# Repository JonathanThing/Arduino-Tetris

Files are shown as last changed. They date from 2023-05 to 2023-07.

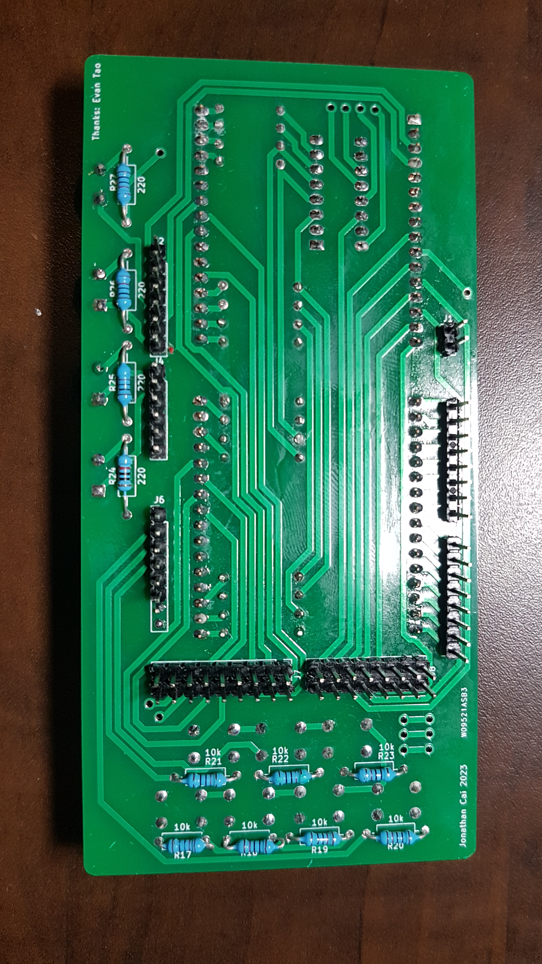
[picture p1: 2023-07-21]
Pictures/Soldered Back PCB.jpg

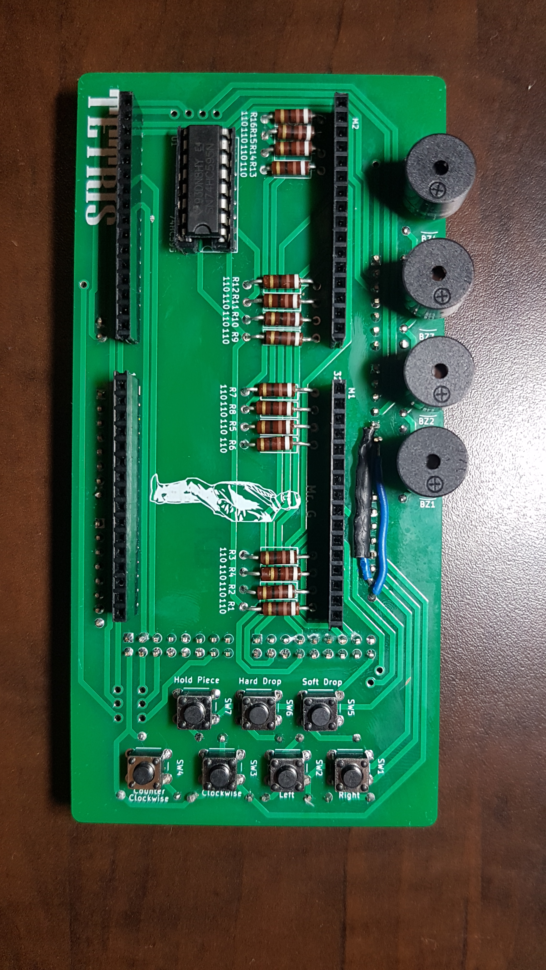
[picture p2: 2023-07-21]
Pictures/Soldered Front PCB.jpg

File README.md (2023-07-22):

# Arduino-Tetris
Tetris on an Arduino Mega

Video Demo: <br />
Arduino Tetris Demo (https://www.youtube.com/watch?v=_YhfdDc1tRE)

This was my Gr.12 Computer Engineering Final project where I designed, created, and programmed Tetris from start to finish.

Software Used:
- KiCAD
- Arduino IDE

Stage 1: Design
- Using KiCad, I created a circuit diagram and PCB layout

Stage 2: Assembly
- I soldered the components onto the PCB, 

Stage 3: Programming
- I programmed Tetris and the music player

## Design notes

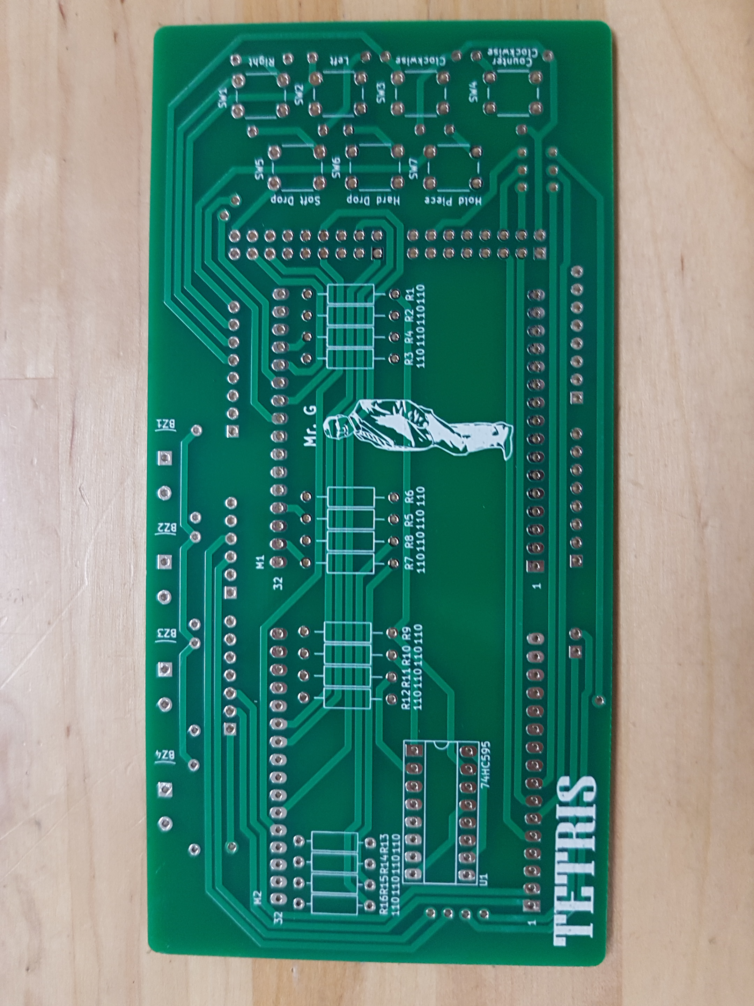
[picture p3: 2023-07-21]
Pictures/Front PCB.jpg

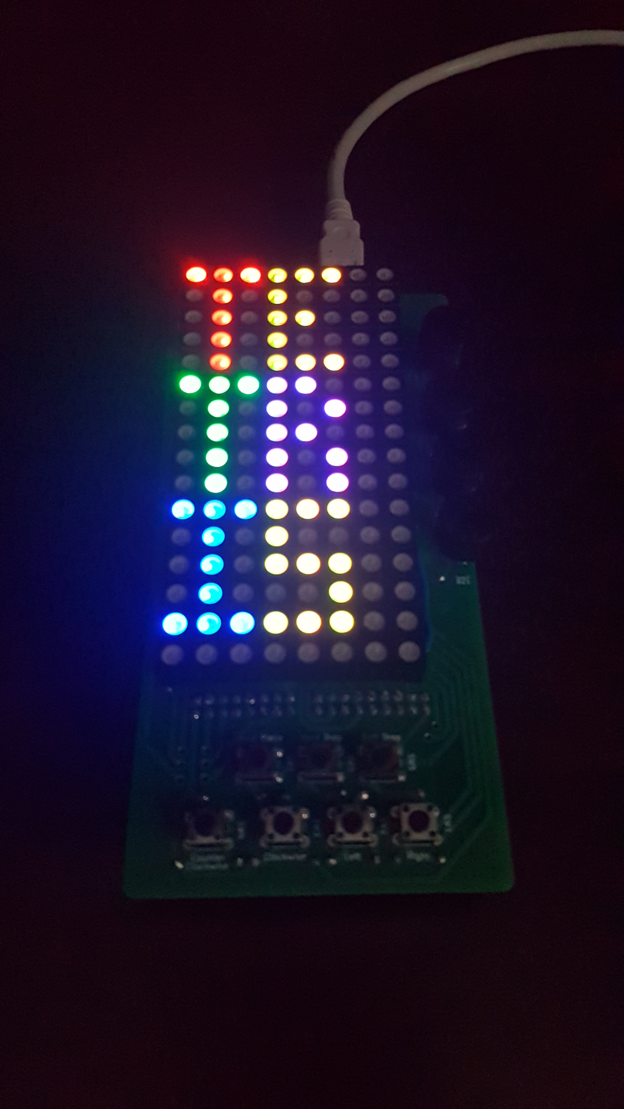
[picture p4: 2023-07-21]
Pictures/Final Project.jpg

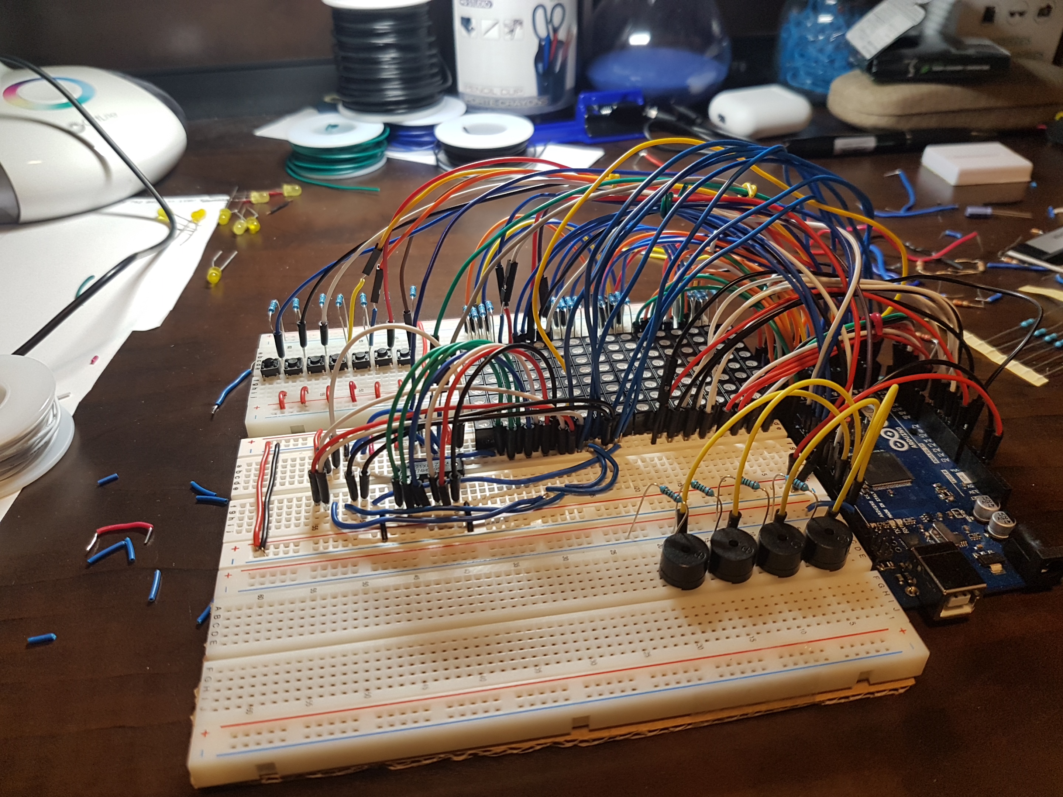
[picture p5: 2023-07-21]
Pictures/Prototype.jpg

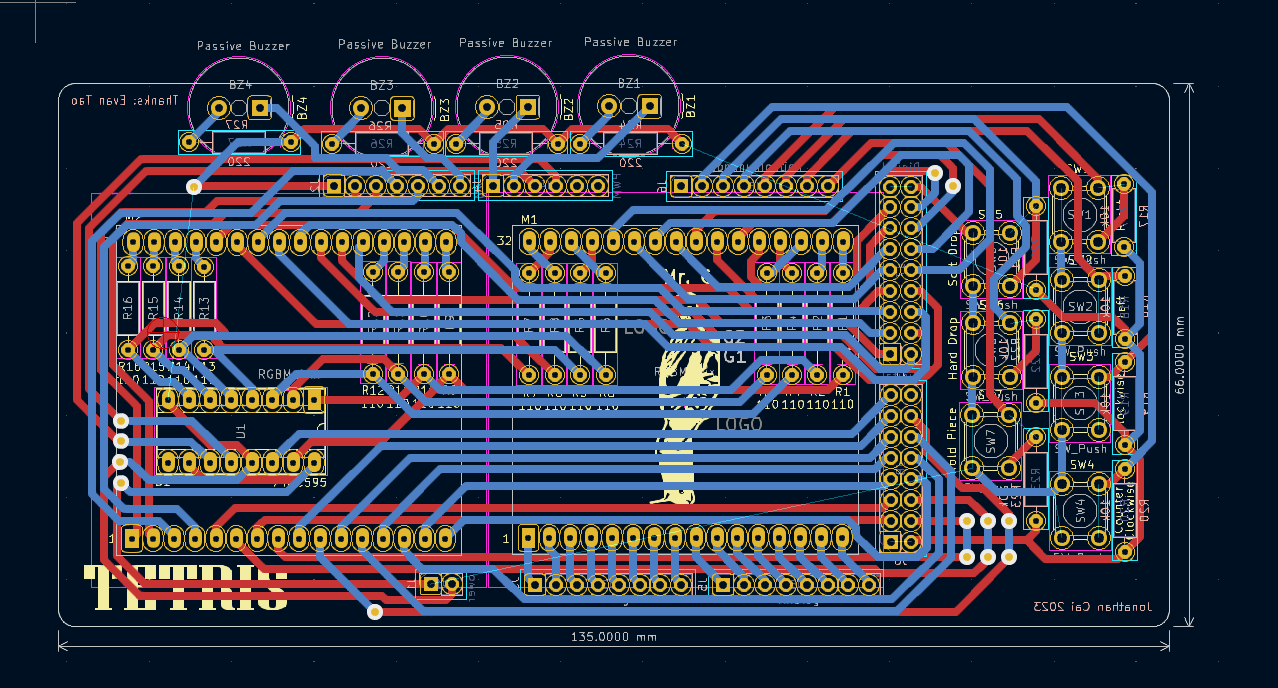
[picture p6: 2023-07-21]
Pictures/PCB Layout.png

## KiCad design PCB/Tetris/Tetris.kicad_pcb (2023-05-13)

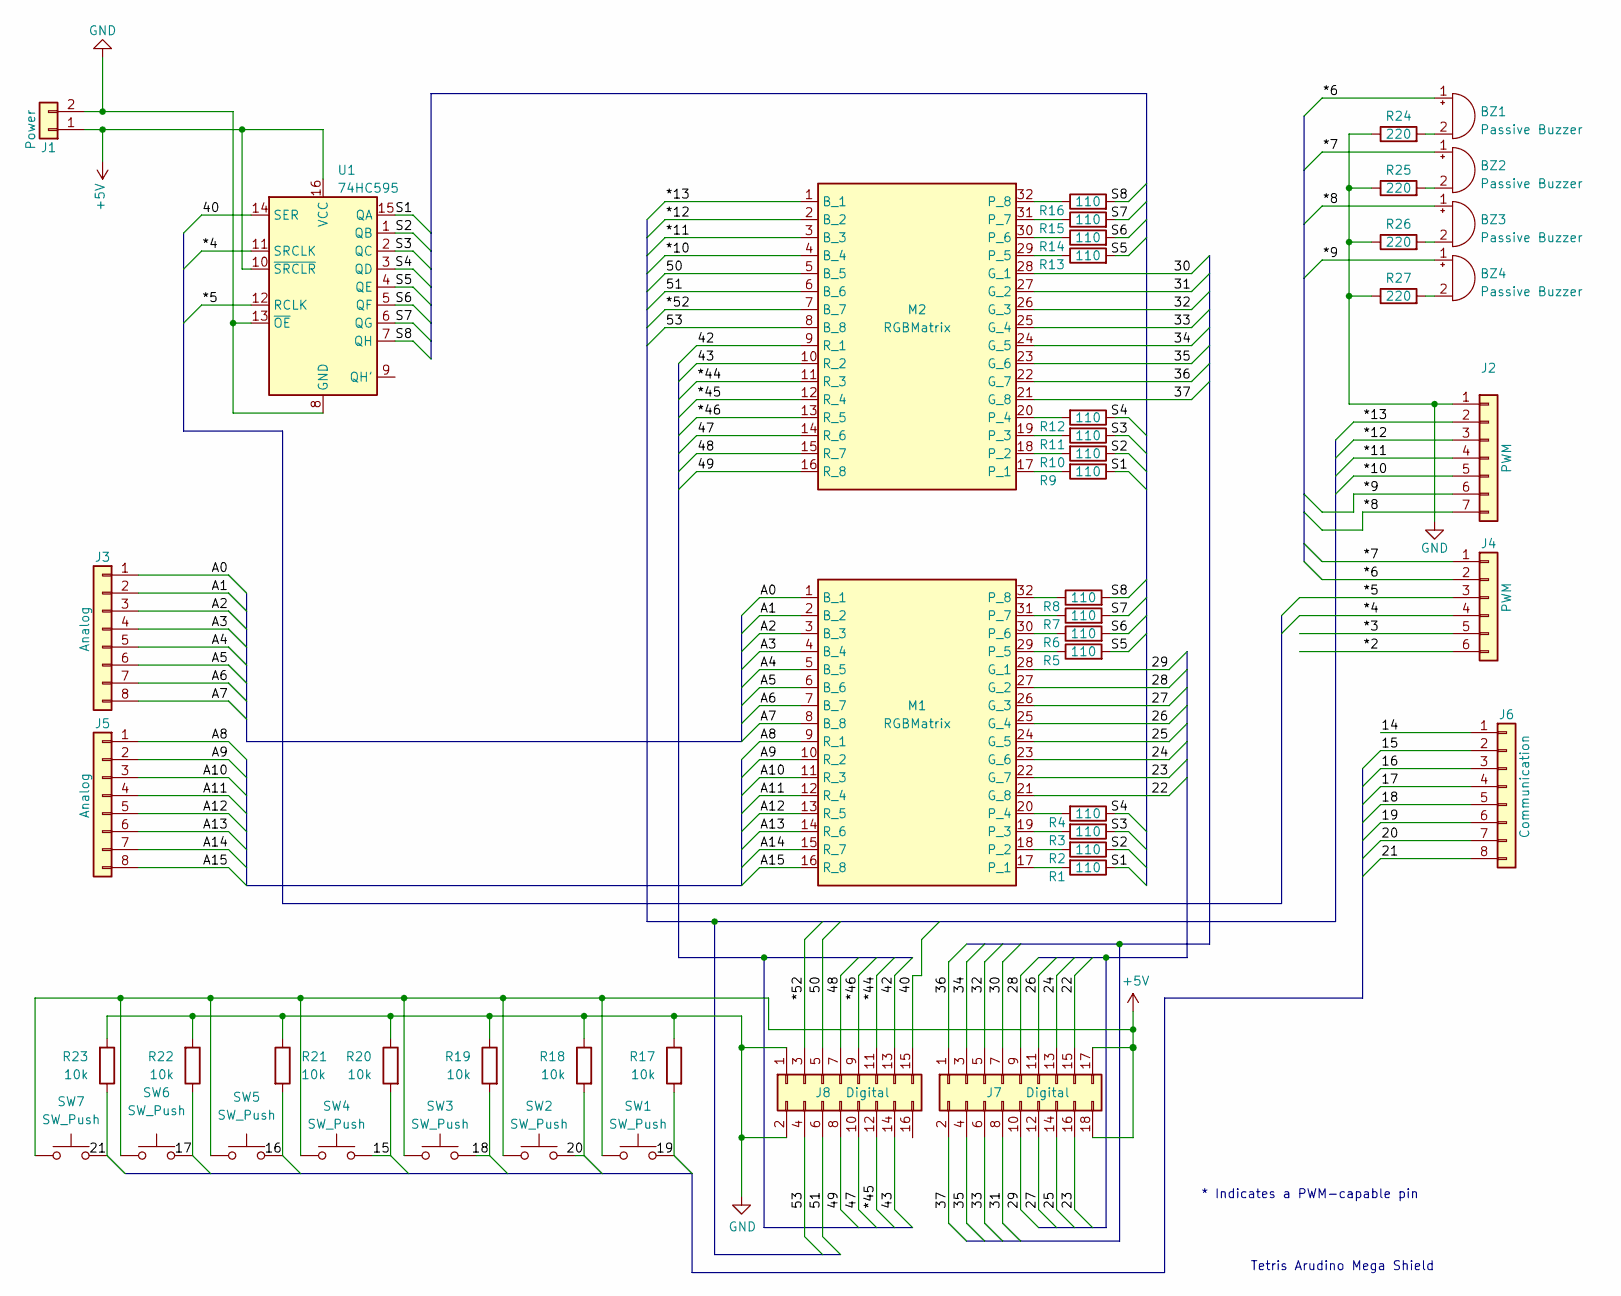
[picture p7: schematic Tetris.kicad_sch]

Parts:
BZ1, BZ2, BZ3, BZ4: Passive Buzzer; Buzzer_TDK_PS1240P02BT_D12.2mm_H6.5mm
J1: Power; PinHeader_1x02_P2.54mm_Vertical
J2: PWM; PinHeader_1x07_P2.54mm_Vertical
J3, J5: Analog; PinHeader_1x08_P2.54mm_Vertical
J4: PWM; PinHeader_1x06_P2.54mm_Vertical
J6: Communication; PinHeader_1x08_P2.54mm_Vertical
J7: Digital; PinHeader_2x09_P2.54mm_Vertical
J8: Digital; PinHeader_2x08_P2.54mm_Vertical
M1, M2: RGBMatrix
R1, R2, R3, R4, R5, R6, R7, R8, R9, R10, R11, R12: 110; R_Axial_DIN0207_L6.3mm_D2.5mm_P12.40mm_Horizontal
R13, R14, R15, R16: 110; R_Axial_DIN0207_L6.3mm_D2.5mm_P10.16mm_Horizontal
R17, R18: 10k; R_Axial_DIN0207_L6.3mm_D2.5mm_P7.62mm_Horizontal
R19, R20, R21, R22, R23: 10k; R_Axial_DIN0207_L6.3mm_D2.5mm_P10.16mm_Horizontal
R24, R25, R26, R27: 220; R_Axial_DIN0207_L6.3mm_D2.5mm_P12.40mm_Horizontal
SW1, SW2, SW3, SW4, SW5, SW6, SW7: SW_Push; SW_PUSH_6mm_H4.3mm
U1: 74HC595; DIP-16_W7.62mm_Socket_LongPads

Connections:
+5V: J1.1, J7.17, J7.18, SW1.2, SW2.2, SW3.2, SW4.2, SW5.2, SW6.2, SW7.2, U1.10 (~SRCLR), U1.16 (VCC)
/14: J6.1
/15: J6.2, R20.2, SW4.1
/16: J6.3, R21.2, SW5.1
/17: J6.4, R22.1, SW6.1
/18: J6.5, R19.2, SW3.1
/19: J6.6, R17.2, SW1.1
/20: J6.7, R18.2, SW2.1
/21: J6.8, R23.1, SW7.1
/22: J7.15, M1.21 (G_8)
/23: J7.16, M1.22 (G_7)
/24: J7.13, M1.23 (G_6)
/25: J7.14, M1.24 (G_5)
/26: J7.11, M1.25 (G_4)
/27: J7.12, M1.26 (G_3)
/28: J7.9, M1.27 (G_2)
/29: J7.10, M1.28 (G_1)
/30: J7.7, M2.28 (G_1)
/31: J7.8, M2.27 (G_2)
/32: J7.5, M2.26 (G_3)
/33: J7.6, M2.25 (G_4)
/34: J7.3, M2.24 (G_5)
/35: J7.4, M2.23 (G_6)
/36: J7.1, M2.22 (G_7)
/37: J7.2, M2.21 (G_8)
/40: J8.15, U1.14 (SER)
/41: J8.16
/42: J8.13, M2.9 (R_1)
/43: J8.14, M2.10 (R_2)
/47: J8.10, M2.14 (R_6)
/48: J8.7, M2.15 (R_7)
/49: J8.8, M2.16 (R_8)
/50: J8.5, M2.5 (B_5)
/51: J8.6, M2.6 (B_6)
/53: J8.4, M2.8 (B_8)
/*2: J4.6
/*3: J4.5
/*4: J4.4, U1.11 (SRCLK)
/*5: J4.3, U1.12 (RCLK)
/*6: BZ1.1 (-), J4.2
/*7: BZ2.1 (-), J4.1
/*8: BZ3.1 (-), J2.7
/*9: BZ4.1 (-), J2.6
/*10: J2.5, M2.4 (B_4)
/*11: J2.4, M2.3 (B_3)
/*12: J2.3, M2.2 (B_2)
/*13: J2.2, M2.1 (B_1)
/*44: J8.11, M2.11 (R_3)
/*45: J8.12, M2.12 (R_4)
/*46: J8.9, M2.13 (R_5)
/*52: J8.3, M2.7 (B_7)
/A0: J3.1, M1.1 (B_1)
/A1: J3.2, M1.2 (B_2)
/A2: J3.3, M1.3 (B_3)
/A3: J3.4, M1.4 (B_4)
/A4: J3.5, M1.5 (B_5)
/A5: J3.6, M1.6 (B_6)
/A6: J3.7, M1.7 (B_7)
/A7: J3.8, M1.8 (B_8)
/A8: J5.1, M1.9 (R_1)
/A9: J5.2, M1.10 (R_2)
/A10: J5.3, M1.11 (R_3)
/A11: J5.4, M1.12 (R_4)
/A12: J5.5, M1.13 (R_5)
/A13: J5.6, M1.14 (R_6)
/A14: J5.7, M1.15 (R_7)
/A15: J5.8, M1.16 (R_8)
/S1: R1.1, R9.1, U1.15 (QA)
/S2: R2.1, R10.1, U1.1 (QB)
/S3: R3.1, R11.1, U1.2 (QC)
/S4: R4.1, R12.1, U1.3 (QD)
/S5: R5.2, R13.2, U1.4 (QE)
/S6: R6.2, R14.2, U1.5 (QF)
/S7: R7.2, R15.2, U1.6 (QG)
/S8: R8.2, R16.2, U1.7 (QH)
GND: J1.2, J2.1, J8.1, J8.2, R17.1, R18.1, R19.1, R20.1, R21.1, R22.2, R23.2, R24.1, R25.1, R26.1, R27.1, U1.8 (GND), U1.13 (~OE)
unnamed: BZ1.2 (+), R24.2
unnamed: BZ2.2 (+), R25.2
unnamed: BZ3.2 (+), R26.2
unnamed: BZ4.2 (+), R27.2
unnamed: M1.17 (P_1), R1.2
unnamed: M1.18 (P_2), R2.2
unnamed: M1.19 (P_3), R3.2
unnamed: M1.20 (P_4), R4.2
unnamed: M1.29 (P_5), R5.1
unnamed: M1.30 (P_6), R6.1
unnamed: M1.31 (P_7), R7.1
unnamed: M1.32 (P_8), R8.1
unnamed: M2.17 (P_1), R9.2
unnamed: M2.18 (P_2), R10.2
unnamed: M2.19 (P_3), R11.2
unnamed: M2.20 (P_4), R12.2
unnamed: M2.29 (P_5), R13.1
unnamed: M2.30 (P_6), R14.1
unnamed: M2.31 (P_7), R15.1
unnamed: M2.32 (P_8), R16.1

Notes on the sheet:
* Indicates a PWM-capable pin
Tetris Arudino Mega Shield

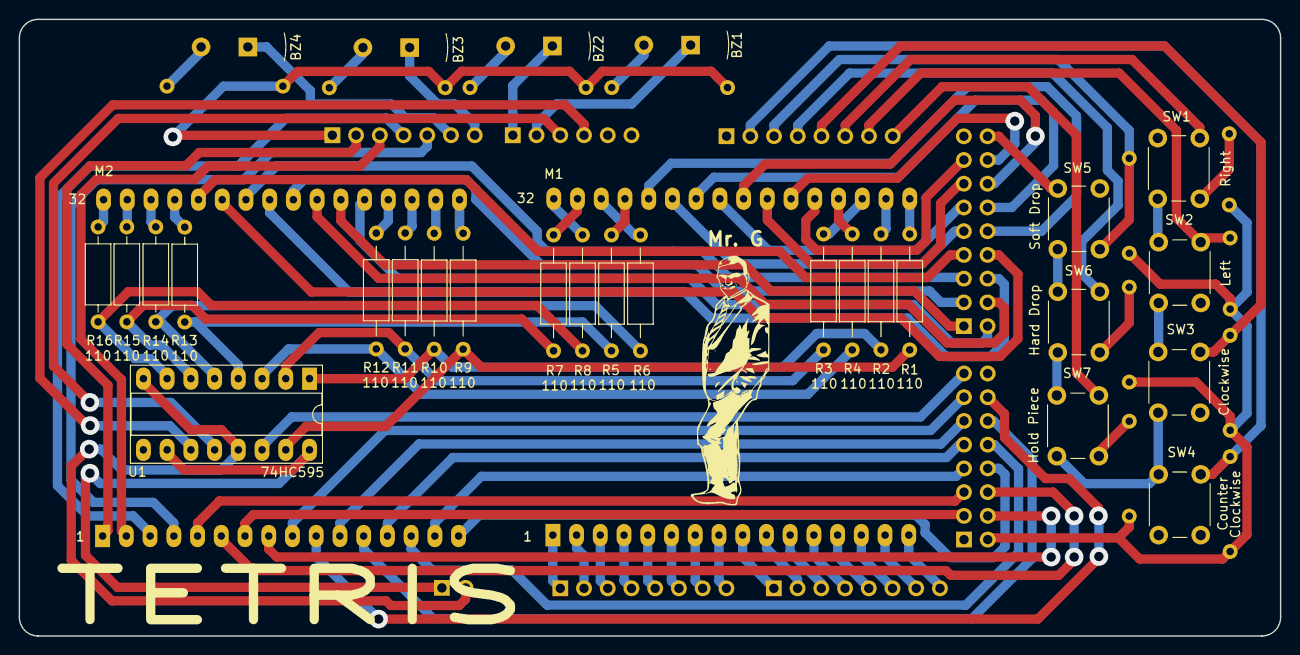
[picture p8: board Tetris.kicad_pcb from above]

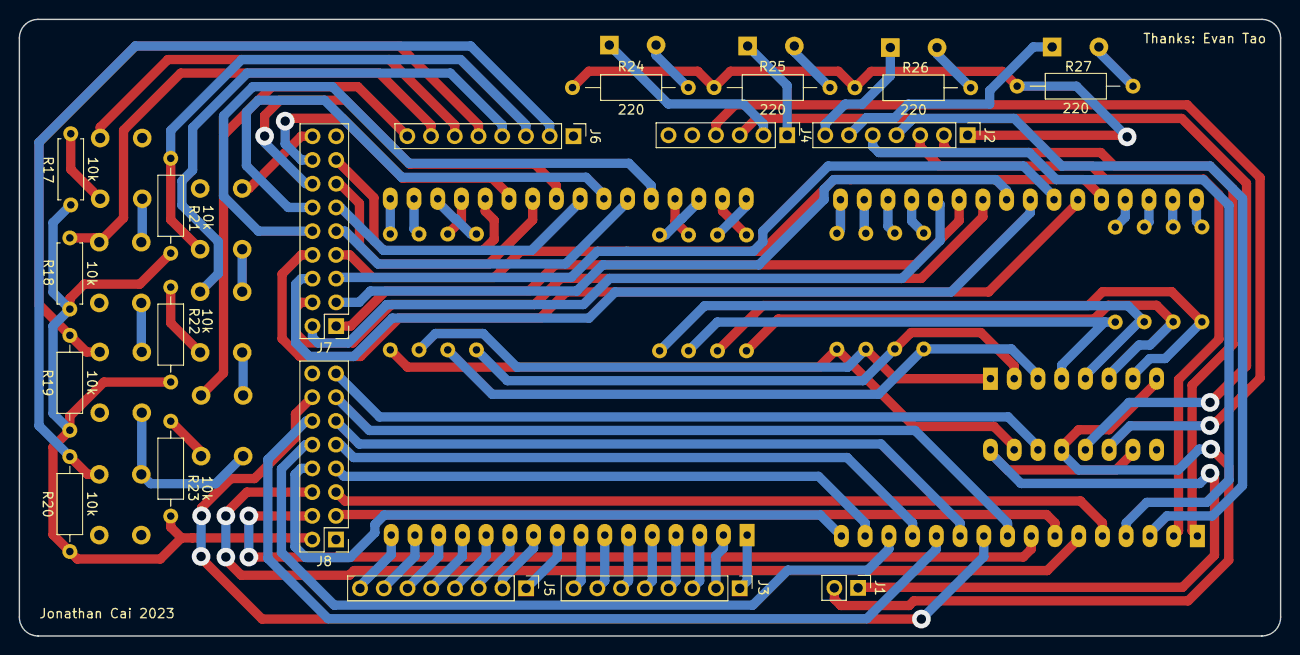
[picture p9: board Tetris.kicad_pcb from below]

Board: 2 copper layers, 135.0 x 66.0 mm, 51 parts (19 on the bottom side), 92 nets.

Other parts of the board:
G1, G2: LOGO

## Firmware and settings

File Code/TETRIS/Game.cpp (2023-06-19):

#include "Game.h"

const byte startX = 2;
const byte startY = 13;
const int defaultFallTime = 750;
int currentX = startX;
int currentY = startY;
byte currentRotation = 0;

long score = 0;
int totalLinesRemoved = 0;
int timePerFall = defaultFallTime;

byte sevenBag[7] = { 0, 1, 2, 3, 4, 5, 6 };

long inputAnchorTime = 0;  // Anchor time for user input
long fallAnchorTime = 0;   // Anchor time for falling
byte nextBlockIndex;

bool gameLost;
bool canHold;
bool emptyHold;
bool placeBlockGracePeriod;

Tetromino currentBlock = I_BLOCK;
Tetromino nextBlock = I_BLOCK;
Tetromino holdBlock = Tetromino();

char gameSpace[8][14];


void removeLines();
void adjustFallSpeed();
void randomizeBag();
void getNextBlock();
void getHoldBlock();
bool checkCollision(int x, int y, byte rotation);
int findLowestSpot();
void placeBlock();
void handleGameInput();
void moveX(int deltaX);
void moveY(int deltaY);
void rotateBlock(bool clockwise);
void hardDrop();
void drawHoldBlock();
void drawNextBlock();
void drawCurrentBlock();
void drawOutlineBlock();
void drawGameSpace();
void endGame();

void initGame(long seed) {
  // Randomizing the game
  Serial.print("Seed: ");
  Serial.println(seed);
  randomSeed(seed);
  randomizeBag();

  // Reseting Variables
  gameLost = false;
  emptyHold = true;
  canHold = true;
  nextBlockIndex = 1;
  currentBlock = blocks[sevenBag[0]];
  nextBlock = blocks[sevenBag[nextBlockIndex]];
  score = 0;
  totalLinesRemoved = 0;
  timePerFall = defaultFallTime;

  // Clearing game space
  for (int i = 0; i < 8; i++) {
    for (int j = 0; j < 14; j++) {
      gameSpace[i][j] = 0;
    }
  }
}

void updateGame() {
  long inputDeltaTime = millis() - inputAnchorTime;
  long fallDeltaTime = millis() - fallAnchorTime;

  if (fallDeltaTime > timePerFall) {
    moveY(-1);
  }
  if (inputDeltaTime > 250) {
    handleGameInput();
    if (inputs > 0) {  // If a button was pressed
      inputAnchorTime = millis();
    }
  }

  drawHoldBlock();
  drawNextBlock();
  drawGameSpace();
  drawOutlineBlock();
  drawCurrentBlock();

  if (gameLost) {
    endGame();
  }
}

void getNextBlock() {
  currentBlock = nextBlock;
  nextBlockIndex++;
  if (nextBlockIndex == 7) {
    randomizeBag();
    nextBlockIndex = 0;
  }
  nextBlock = blocks[sevenBag[nextBlockIndex]];

  // Reset Values for new Block
  placeBlockGracePeriod = true;
  canHold = true;
  currentX = startX;
  currentY = startY;
  currentRotation = 0;
  fallAnchorTime = millis();
}

void randomizeBag() {
  for (int i = 0; i < 7; i++) {
    byte index = random(7);
    byte temp = sevenBag[index];
    sevenBag[index] = sevenBag[i];
    sevenBag[i] = temp;
  }
}

void getHoldBlock() {
  if (canHold) {
    if (emptyHold) {
      emptyHold = false;
      holdBlock = currentBlock;
      getNextBlock();
    } else {
      Tetromino tempBlock = currentBlock;
      currentBlock = holdBlock;
      holdBlock = tempBlock;
      canHold = false;
    }

    // Reset Values for new Block
    placeBlockGracePeriod = true;
    currentX = startX;
    currentY = startY;
    currentRotation = 0;
    fallAnchorTime = millis();
  }
}

void handleGameInput() {
  if (inputs & 1 << 0) {  // Right
    moveX(1);
  } else if (inputs & 1 << 1) {  // Left
    moveX(-1);
  } else if (inputs & 1 << 2) {  // Clockwise
    rotateBlock(true);
  } else if (inputs & 1 << 3) {  // Counter Clockwise
    rotateBlock(false);
  } else if (inputs & 1 << 4) {  // Soft Drop
    moveY(-1);
  } else if (inputs & 1 << 5) {  // Hard Drop
    hardDrop();
  } else if (inputs & 1 << 6) {  // Hold Block
    getHoldBlock();
  }
}

// Given parameters, check if currentBlock can be there
bool checkCollision(int x, int y, byte rotation) {
  for (int rows = 0; rows < 4; rows++) {
    for (int cols = 0; cols < 4; cols++) {
      int tileX = x + cols;
      int tileY = y - rows;

      if (currentBlock.tiles[rotation] & (1 << (rows * 4 + cols))) {
        if (!(0 <= tileY && tileY <= 13 && 0 <= tileX && tileX <= 7) || gameSpace[tileX][tileY] > 0) {
          return false;
        }
      }
    }
  }

  return true;
}

void moveX(int deltaX) {
  int tempX = currentX + deltaX;
  if (checkCollision(tempX, currentY, currentRotation)) {
    currentX += deltaX;
  }
}

void moveY(int deltaY) {
  int tempY = currentY + deltaY;
  if (checkCollision(currentX, tempY, currentRotation)) {
    currentY += deltaY;
  } else {
    if (!placeBlockGracePeriod || (currentX == startX && currentY == startY)) {
      placeBlock();
    }
    placeBlockGracePeriod = false;
  }
  fallAnchorTime = millis();
}

void rotateBlock(bool clockwise) {
  byte tempRotation = currentRotation;
  if (clockwise) {
    tempRotation++;
    if (tempRotation > 3) {
      tempRotation = 0;
    }
  } else {
    tempRotation--;
    if (tempRotation > 3) {
      tempRotation = 3;
    }
  }

  if (checkCollision(currentX, currentY, tempRotation)) {
    currentRotation = tempRotation;
  }
}

void placeBlock() {
  if (currentX == startX && currentY == startY) {  // If you lose
    gameLost = true;
    return;
  }

  for (int rows = 0; rows < 4; rows++) {
    for (int cols = 0; cols < 4; cols++) {
      int tileX = currentX + cols;
      int tileY = currentY - rows;

      if (currentBlock.tiles[currentRotation] & (1 << (rows * 4 + cols))) {
        gameSpace[tileX][tileY] = currentBlock.symbol;
      }
    }
  }

  removeLines();
  getNextBlock();
}

// Remove Full lines and handles the effects of it
void removeLines() {
  // Remove Lines
  byte remainingLines[14];
  byte numberOfLines = 0;
  byte lineIndex = 0;
  for (int y = 0; y < 14; y++) {
    bool full = true;
    for (int x = 0; x < 8; x++) {
      if (gameSpace[x][y] == 0) {
        full = false;
        break;
      }
    }
    if (full) {
      numberOfLines++;
    } else {
      remainingLines[lineIndex] = y;
      lineIndex++;
    }
  }

  // Update Score, totalLinesremoved, and fall speed
  totalLinesRemoved += numberOfLines;
  adjustFallSpeed();
  switch (numberOfLines) {
    case 1:
      score += 100;
      break;
    case 2:
      score += 300;
      break;
    case 3:
      score += 500;
      break;
    case 4:
      score += 800;
      break;
  }

  // Update Display
  char tempArray[8][14];

  // Create temporary array
  for (int i = 0; i < lineIndex; i++) {
    for (int x = 0; x < 8; x++) {
      tempArray[x][i] = gameSpace[x][remainingLines[i]];
    }
  }
  for (int i = lineIndex; i < 14; i++) {
    for (int x = 0; x < 8; x++) {
      tempArray[x][i] = 0;
    }
  }

  // Trasnfer temporary array to gamespace
  for (int y = 0; y < 14; y++) {
    for (int x = 0; x < 8; x++) {
      gameSpace[x][y] = tempArray[x][y];
    }
  }
}

// Find the lowestY the current block can go to
int findLowestSpot() {
  int lowestY = currentY;
  if (!checkCollision(currentX, lowestY, currentRotation)) {
    return lowestY;
  } else {
    while (checkCollision(currentX, lowestY, currentRotation)) {
      lowestY--;
    }
    lowestY++;
    return lowestY;
  }
}
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

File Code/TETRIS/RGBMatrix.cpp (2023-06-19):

#include "RGBMatrix.h"

#define MAX_INT 0xFFFF
#define dataPin 40
#define shiftClockPin 4
#define storageClockPin 5

byte currentRow;

// Local Functions
void cyclePower();
void drawRow();
void writeColour(int colour, int value);
void writeShiftRegister(byte value);
// Helper Functions
void writeDataPin(bool value);
void writeShiftClockPin(bool value);
void writeStorageClockPin(bool value);
byte reverseByte(byte input);

void drawDisplay() {
  for (int i = 0; i < 8; i++) {
    cyclePower();
    drawRow();
  }
}

void setupRGBMatrix() {
  DDRA = B11111111;
  DDRB = B11111111;
  DDRC = B11111111;
  DDRF = B11111111;
  DDRK = B11111111;
  DDRL = B11111111;

  PORTA = B11111111;
  PORTB = B11111111;
  PORTC = B11111111;
  PORTF = B11111111;
  PORTK = B11111111;
  PORTL = B11111111;

  pinMode(dataPin, OUTPUT);
  pinMode(storageClockPin, OUTPUT);
  pinMode(shiftClockPin, OUTPUT);
  writeShiftRegister(0);
  currentRow = 0;
}

// RGB Matrix
// Power    Shift Register
// Red 1    Port K (Not inverted) MSB
// Green 1  Port A (Inverted) LSB
// Blue 1   Port F (Not Inverted) MSB
// Red 2    Port L (Inverted) LSB
// Green 2  Port C (Inverted) LSB
// Blue 2   Port B (Inverted) LSB
void writeColour(int colour, int value) {
  if (colour == 0) {  // Red
    PORTL = (byte)(value >> 8 & 255);
    PORTK = reverseByte((byte)value);  // PORT K IS NOT INVERTED
  } else if (colour == 1) {            // Green
    PORTC = (byte)(value >> 8 & 255);
    PORTA = (byte)(value);
  } else {  // Blue
    PORTB = (byte)(value >> 8 & 255);
    PORTF = reverseByte((byte)value);  // PORT F IS NOT INVERTED
  }
}

void writeShiftRegister(byte value) {
  for (int i = 7; i >= 0; i--) {
    writeDataPin(value & (1 << i));
    writeShiftClockPin(LOW);
    writeShiftClockPin(HIGH);
  }
  writeStorageClockPin(LOW);
  writeStorageClockPin(HIGH);
}

void drawRow() {
  for (int colour = 0; colour < 3; colour++) {
    for (int i = 0; i < COLOUR_MAX_VALUE; i++) {  // Resolution
      int bitMask = 0;
      for (int j = 0; j < 16; j++) {
        bitMask |= (display[j][currentRow]->getColourValue(colour) >= (i + 1));
        if (j != 15) {
          bitMask <<= 1;
        }
      }
      writeColour(colour, ~bitMask);
      if (colour == 0) {
        delayMicroseconds(25);
      }
    }
    writeColour(colour, MAX_INT);
  }
}

void cyclePower() {
  currentRow++;
  if (currentRow >= 8) {
    currentRow = 0;
  }

  writeShiftClockPin(LOW);
  writeStorageClockPin(LOW);
  writeDataPin(currentRow == 0);
  writeShiftClockPin(HIGH);
  writeStorageClockPin(HIGH);
}

void writeDataPin(bool value) {
  if (value) {
    PORTG = PORTG | B00000010;
  } else {
    PORTG = PORTG & B11111101;
  }
}

void writeShiftClockPin(bool value) {
  if (value) {
    PORTG = PORTG | B00100000;
  } else {
    PORTG = PORTG & B11011111;
  }
}

void writeStorageClockPin(bool value) {
  if (value) {
    PORTE = PORTE | B00001000;
  } else {
    PORTE = PORTE & B11110111;
  }
}

byte reverseByte(byte input) {
  byte output = input;
  for (int i = 0; i < 8; i++) {
    output <<= 1;
    output |= input & 1;
    input >>= 1;
  }
  return output;
}

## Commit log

2023-05-02 Added PCB work to sync
    [Tetris.kicad_pcb, Tetris.kicad_sch]
2023-05-02 something happened
    [Tetris.kicad_pcb, Tetris.kicad_sch]
2023-05-02 Schematics and sync
    [Tetris.kicad_sch]
2023-05-03 Sync change
    [Tetris.kicad_pcb, Tetris.kicad_sch]
2023-05-05 Making diabolical progress
    [Tetris.kicad_sch, Tetris_Copy.kicad_pcb, Tetris_Copy_2.kicad_pcb]
2023-05-06 Saving progress
    [Mega.kicad_pcb, Mega.kicad_sch, Tetris_Copy_3.kicad_pcb]
2023-05-06 Finished PCB
    Finish PCB,
    will still have to double check it
    [Tetris.kicad_pcb]
2023-05-06 Added funnyjoke
    [Tetris.kicad_pcb]
2023-05-06 Sync changes
    [Tetris.kicad_pcb, Tetris.kicad_sch]
2023-05-10 Small Changes
    [Tetris.kicad_pcb, Tetris.kicad_sch]
2023-05-10 Crunch time
    [Tetris_V2.kicad_sch]
2023-05-10 sync hcnages
    [Tetris.kicad_sch, Tetris_V2.kicad_sch]
2023-05-11 MASSIVE PROGRESS
    Redesign PCB to use ports
    [Tetris.kicad_pcb, Tetris.kicad_sch]
2023-05-13 Synch Changes? Idk
    [Tetris-B_Cu.gbr, Tetris-B_Silkscreen.gbr, Tetris-Edge_Cuts.gbr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]
2023-05-14 brain damage
    I run away for this today
    [Tetris.kicad_sch]
2023-05-23 sync random buggy code
    [Game.cpp, RGBMatrix.cpp]
2023-06-15 Sync changes
    Implemented block collision etc
    [Colour.cpp, Game.cpp, RGBMatrix.cpp]
2023-06-18 Saving Progress for rewrite
    Going to implement interrupts. Not sure if saving this is wroth it since its literally just one line :skull
2023-07-21 Cleaned up and tidy repository
    Removed duplicated/unwanted PCB files,
    Added pictures for read me
    [Mega.kicad_pcb, Mega.kicad_sch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]
